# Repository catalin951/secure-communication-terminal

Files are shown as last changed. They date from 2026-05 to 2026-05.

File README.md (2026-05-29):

# Secure Communication Terminal 📻🔒

A fully digital, hardware-secured wireless communication device based on the ESP32 microcontroller. Unlike a classic analog radio station, this device allows real-time voice capture, P2P transmission, and playback **only** if the user passes a biometric authentication filter. 

The system utilizes an ESP32 for processing, an AS608 fingerprint sensor for Zero-Trust access control, and dedicated I2S peripherals for pure digital audio transmission via the ESP-NOW protocol.

## ⚠️ CRITICAL SECURITY CONFIGURATION ⚠️

If you are cloning this repository to build your own terminals, you **MUST** update the following network and security variables in `src/main.cpp` before flashing the code:

1. **Target MAC Address (`peerAddress`):** ESP-NOW requires the exact physical MAC address of the destination device. You must change the `peerAddress[]` array in the code of "Terminal A" to match the MAC of "Terminal B", and vice versa.
2. **AES-128 Secret Key (`secretKey`):** The system uses ESP-NOW's native MAC-layer encryption. You **MUST** change the default 16-byte `secretKey[16]` array to your own random hex values. This key acts as your Pre-Shared Key (PMK) and must be identical on both devices to establish a secure link. Do not use the default repository key!

## Hardware Requirements

To build one terminal, you need the following components:
* 1x **ESP32 DevKit V1** (WROOM-32)
* 1x **AS608** Optical Fingerprint Sensor (UART)
* 1x **INMP441** Digital Omnidirectional Microphone (I2S)
* 1x **MAX98357A** Class D Audio Amplifier (I2S)
* 1x **SSD1306** 0.96" Monochrome OLED Display (I2C)
* 1x 1W Mini Speaker (Analog)
* 3x Tactile Push Buttons (PTT, Admin, Reset)
* 1x Battery Holder (4x AA slots) + 4x NiMH 1.2V Rechargeable Cells
* Custom Enclosure / Breadboard Assembly

## Pinout Mapping

| Component | ESP32 Pin | Signal Type |
| :--- | :--- | :--- |
| **Power (VIN)** | `VIN` | 4.8V Raw Power (Amp & ESP32) |
| **AS608 (RX/TX)** | `D16` / `D17` | UART2 |
| **INMP441 (WS/SCK/SD)** | `D33` / `D18` / `D32` | I2S0 (Microphone) |
| **MAX98357A (WS/BCLK/DIN)** | `D26` / `D27` / `D14` | I2S1 (Amplifier) |
| **SSD1306 (SDA/SCL)** | `D21` / `D22` | I2C |
| **PTT Button** | `D13` | GPIO (INPUT_PULLUP) |
| **Reset Button** | `D19` | GPIO (INPUT_PULLUP) |
| **Admin Button** | `D23` | GPIO (INPUT_PULLUP) |

## Access Control & FSM Logic

The terminal operates based on a strict Finite State Machine (FSM):
* **ST_LOCKED:** The device is isolated. The amplifier is muted (injecting digital zeroes to prevent hiss), and the system waits for biometric validation. Incoming transmissions trigger a hardware beep but audio is blocked.
* **ST_UNLOCKED:** Reached after a valid General User fingerprint match. Unlocks full Two-Way communication for a 2-minute session.
* **ST_ADMIN:** Triggered exclusively by Fingerprint ID 1. Allows enrollment of new users (short press) or complete database wipe (long press).
* **ST_TRANSMIT:** Half-Duplex mode. Pushing the PTT button samples 32-bit audio from the INMP441, truncates it to 16-bit to maximize the ESP-NOW payload (240 bytes), and streams it over the encrypted link. 

## Development & Compilation

This project is built using **PlatformIO**. 
1. Clone the repository.
2. Open the project folder in VS Code with the PlatformIO extension installed.
3. Update the MAC addresses and AES keys.
4. Compile and upload to your ESP32 boards using `Upload`.
5. Note: The project leverages the `driver/i2s_std.h` API from the ESP-IDF natively within the Arduino framework.

## Additional Links:
1. Page with more information about the project: https://ocw.cs.pub.ro/courses/pm/prj2026/theodor_ioan.buliga/catalin.manole1211
2. Demo of the project: https://www.youtube.com/shorts/ny9w-C_flPQ
## License

This project is licensed under the [MIT License](LICENSE) - see the LICENSE file for details.

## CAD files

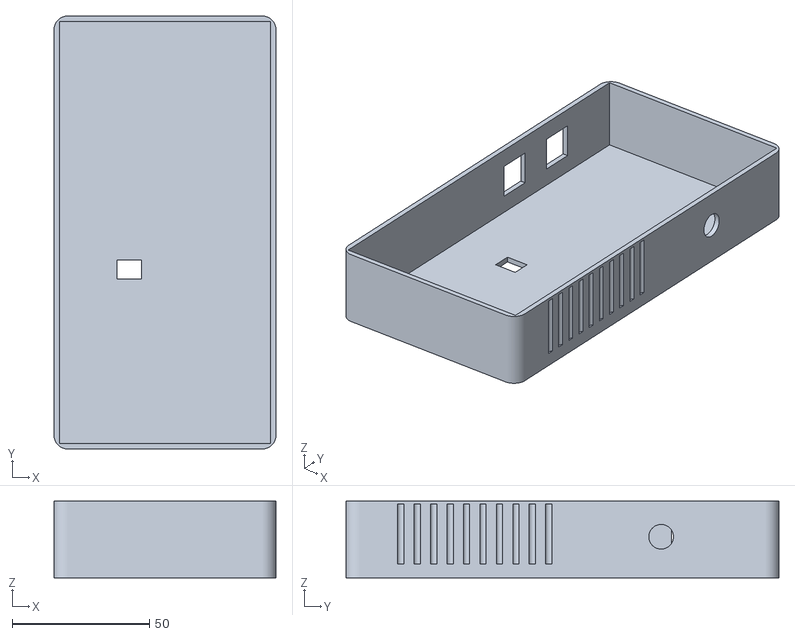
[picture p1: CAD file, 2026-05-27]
enclosure/body.stl
81.0 x 158.0 x 28.0

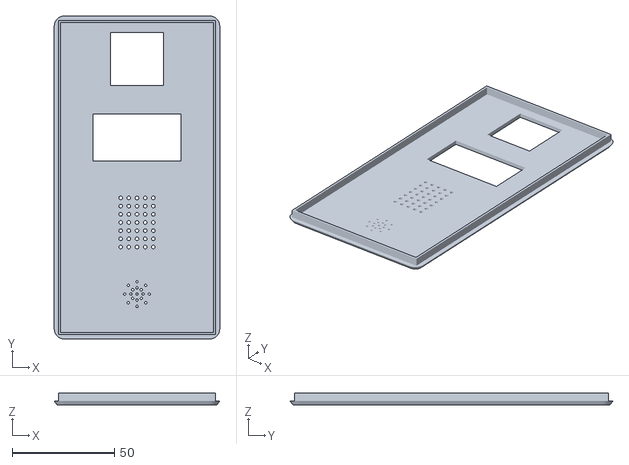
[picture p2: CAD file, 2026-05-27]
enclosure/cover.stl
81.0 x 158.0 x 6.00

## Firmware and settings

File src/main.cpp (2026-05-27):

#include <Arduino.h>
#include <Wire.h>
#include <Adafruit_GFX.h>
#include <Adafruit_SSD1306.h>
#include <Adafruit_Fingerprint.h>
#include "driver/i2s_std.h"
#include "driver/gpio.h"
#include "freertos/FreeRTOS.h"
#include "freertos/task.h"
#include "freertos/queue.h"
#include <esp_now.h>
#include <WiFi.h>

// 1. ESP-NOW TARGET CONFIGURATION
// uint8_t peerAddress[] = {0x88, 0xF1, 0x55, 0x31, 0x81, 0x64};
// const char* myName = "BRAVO";

uint8_t peerAddress[] = {0x88, 0xF1, 0x55, 0x32, 0x75, 0xCC};
const char* myName = "ALPHA";

// Secret AES-128 key - 16 bytes!
// Must be identical on both devices
uint8_t secretKey[16] = {0x1A, 0x2B, 0x3C, 0x4D, 0x5E, 0x6F, 0x70, 0x81, 0x92, 0xA3, 0xB4, 0xC5, 0xD6, 0xE7, 0xF8, 0x09};

// 2. HARDWARE CONFIGURATION

// OLED
#define SCREEN_WIDTH 128
#define SCREEN_HEIGHT 64
Adafruit_SSD1306 display(SCREEN_WIDTH, SCREEN_HEIGHT, &Wire, -1);

// FINGERPRINT
#define FP_RX 16
#define FP_TX 17
HardwareSerial fpSerial(2);
Adafruit_Fingerprint finger = Adafruit_Fingerprint(&fpSerial);

// I2S MIC
#define PIN_I2S_WS   GPIO_NUM_33
#define PIN_I2S_SCK  GPIO_NUM_18
#define PIN_I2S_SD   GPIO_NUM_32
#define I2S_PORT_MIC I2S_NUM_0

// I2S SPEAKER
#define PIN_SPK_WS   GPIO_NUM_26
#define PIN_SPK_BCLK GPIO_NUM_27
#define PIN_SPK_DIN  GPIO_NUM_14
#define I2S_PORT_SPK I2S_NUM_1

i2s_chan_handle_t rx_handle = NULL;
i2s_chan_handle_t tx_handle = NULL;

// BUTTONS
#define PIN_BTN_PTT   13
#define PIN_BTN_RESET 19
#define PIN_BTN_ADMIN 23

// 3. SYSTEM AND NETWORK VARIABLES
enum SystemState { STATE_LOCKED, STATE_WAIT_ADMIN, STATE_ADMIN_MENU, STATE_LIVE_STREAM };
SystemState currentState = STATE_LOCKED;

// UI Logic
enum UIMode { UI_NONE, UI_SENDING, UI_RECEIVING, UI_RECEIVED_PACKET };
UIMode currentUI = UI_NONE;
unsigned long lastPacketTime = 0;

// Async Radio Packet Tracker for Locked Notification
volatile unsigned long lastPacketRxTime = 0;

// Admin Logic Variables
unsigned long adminSessionStart = 0;
bool adminBtnPressed = false;
unsigned long adminBtnPressStart = 0;

// Audio packet structure (Max 250 bytes for ESP-NOW)
#define AUDIO_SAMPLES 120 
typedef struct {
    int16_t audioData[AUDIO_SAMPLES];
} audio_packet_t;

audio_packet_t txPacket;
esp_now_peer_info_t peerInfo;

// Queue for received audio
QueueHandle_t audioQueue;

// 4. FUNCTIONS AND CALLBACKS

void setupI2S() {
    // Config Mic (I2S RX)
    i2s_chan_config_t rx_chan_cfg = I2S_CHANNEL_DEFAULT_CONFIG(I2S_PORT_MIC, I2S_ROLE_MASTER);
    i2s_new_channel(&rx_chan_cfg, NULL, &rx_handle);
    i2s_std_config_t rx_std_cfg = {
        .clk_cfg = I2S_STD_CLK_DEFAULT_CONFIG(16000), 
        .slot_cfg = I2S_STD_PHILIPS_SLOT_DEFAULT_CONFIG(I2S_DATA_BIT_WIDTH_32BIT, I2S_SLOT_MODE_MONO), 
        .gpio_cfg = { .mclk = I2S_GPIO_UNUSED, .bclk = PIN_I2S_SCK, .ws = PIN_I2S_WS, .dout = I2S_GPIO_UNUSED, .din = PIN_I2S_SD, .invert_flags = {0} },
    };
    i2s_channel_init_std_mode(rx_handle, &rx_std_cfg);
    i2s_channel_enable(rx_handle);

    // Config Speaker (I2S TX)
    i2s_chan_config_t tx_chan_cfg = I2S_CHANNEL_DEFAULT_CONFIG(I2S_PORT_SPK, I2S_ROLE_MASTER);
    i2s_new_channel(&tx_chan_cfg, &tx_handle, NULL);
    i2s_std_config_t tx_std_cfg = {
        .clk_cfg = I2S_STD_CLK_DEFAULT_CONFIG(16000), 
        .slot_cfg = I2S_STD_PHILIPS_SLOT_DEFAULT_CONFIG(I2S_DATA_BIT_WIDTH_16BIT, I2S_SLOT_MODE_MONO), 
        .gpio_cfg = { .mclk = I2S_GPIO_UNUSED, .bclk = PIN_SPK_BCLK, .ws = PIN_SPK_WS, .dout = PIN_SPK_DIN, .din = I2S_GPIO_UNUSED, .invert_flags = {0} },
    };
    i2s_channel_init_std_mode(tx_handle, &tx_std_cfg);
}

// ESP-NOW Receive Callback
void OnDataRecv(const esp_now_recv_info_t *esp_now_info, const uint8_t *incomingData, int len) {
    if (len == sizeof(audio_packet_t)) {
        lastPacketRxTime = millis(); // Track incoming traffic timestamp globally
        
        // Only queue audio data if the system is unlocked and live
        if (currentState == STATE_LIVE_STREAM) {
            audio_packet_t rxPacket;
            memcpy(&rxPacket, incomingData, sizeof(rxPacket));
            xQueueSendFromISR(audioQueue, &rxPacket, NULL);
        }
    }
}

// MASTER UI DRAWING FUNCTION
void drawUI(const char* headerTitle, const char* mainText, const char* footerText) {
    display.clearDisplay();
    
    // 1. Header Area
    display.setTextSize(1);
    display.setTextColor(WHITE);
    display.setCursor(0, 0);
    display.print(headerTitle); 
    display.print(" | "); 
    display.print(myName);
    display.drawLine(0, 10, 128, 10, WHITE);
    
    // 2. Main Body Area
    display.setTextSize(2);
    int textWidth = strlen(mainText) * 12; 
    int xPos = (128 - textWidth) / 2;
    if (xPos < 0) xPos = 0; 
    display.setCursor(xPos, 25);
    display.print(mainText);
    
    // 3. Footer Area
    display.drawLine(0, 52, 128, 52, WHITE);
    display.setTextSize(1);
    display.setCursor(0, 55);
    display.print(footerText);
    
    display.display();
}

void drawLockedScreen() {
    drawUI("TERMINAL NAME", "LOCKED", "Scan finger to unlock");
}

void drawAdminMenu() {
    drawUI("ADMIN MENU", "SYSTEM OK", "1x: Add | 3s: Delete");
}

bool enrollRoutine(uint8_t id) {
    int p = -1;
    drawUI("ENROLL 1/3", "PUT FINGER", "Scan ID 2");
    
    while (p != FINGERPRINT_OK) {
        p = finger.getImage();
        if (digitalRead(PIN_BTN_RESET) == LOW) ESP.restart(); 
    }
    p = finger.image2Tz(1);
    if (p != FINGERPRINT_OK) return false;
    
    drawUI("ENROLL 2/3", "LIFT", "Wait for scanner...");
    delay(2000);
    p = 0;
    while (p != FINGERPRINT_NOFINGER) {
        p = finger.getImage();
    }
    
    drawUI("ENROLL 3/3", "TAP AGAIN", "Confirming...");
    p = -1;
    while (p != FINGERPRINT_OK) {
        p = finger.getImage();
        if (digitalRead(PIN_BTN_RESET) == LOW) ESP.restart();
    }
    p = finger.image2Tz(2);
    if (p != FINGERPRINT_OK) return false;
    
    p = finger.createModel();
    if (p != FINGERPRINT_OK) return false;
    
    p = finger.storeModel(id);
    if (p != FINGERPRINT_OK) return false;
    
    return true;
}

// 5. SETUP
void setup() {
    Serial.begin(115200);
    delay(1000);

    pinMode(PIN_BTN_PTT, INPUT_PULLUP);
    pinMode(PIN_BTN_RESET, INPUT_PULLUP);
    pinMode(PIN_BTN_ADMIN, INPUT_PULLUP);

    if(!display.begin(SSD1306_SWITCHCAPVCC, 0x3C)) Serial.println("[DEBUG] OLED Error!");
    drawLockedScreen();

    fpSerial.begin(57600, SERIAL_8N1, FP_RX, FP_TX);
    audioQueue = xQueueCreate(10, sizeof(audio_packet_t));

    WiFi.mode(WIFI_STA);
    WiFi.disconnect();
    esp_now_init();
    
    esp_now_set_pmk(secretKey);
    esp_now_register_recv_cb(OnDataRecv);
    
    memcpy(peerInfo.peer_addr, peerAddress, 6);
    peerInfo.channel = 0;  
    peerInfo.encrypt = true; 
    memcpy(peerInfo.lmk, secretKey, 16); 
    
    esp_now_add_peer(&peerInfo);

    setupI2S();
}

// 6. MAIN LOOP
void loop() {
    if (digitalRead(PIN_BTN_RESET) == LOW) {
        ESP.restart();
    }

    switch (currentState) {
        
        case STATE_LOCKED: {
            // Check if there is active incoming radio traffic right now
            bool isIncoming = (millis() - lastPacketRxTime < 500);
            static bool lastIncomingState = false;

            // Update UI dynamically if transmission state changes while locked
            if (isIncoming != lastIncomingState) {
                lastIncomingState = isIncoming;
                if (isIncoming) {
                    drawUI("ALERT", "INCOMING", "Scan finger to listen!");
                    
                    // Generate a quick hardware alert beep tone
                    i2s_channel_enable(tx_handle);
                    int16_t alertTone[AUDIO_SAMPLES];
                    for(int i = 0; i < AUDIO_SAMPLES; i++) {
                        alertTone[i] = (i % 20 < 10) ? 4000 : -4000; // 800Hz square wave
                    }
                    size_t w;
                    // Play 8 short bursts for an audible "ping" notification
                    for(int bursts = 0; bursts < 8; bursts++) {
                        i2s_channel_write(tx_handle, alertTone, sizeof(alertTone), &w, portMAX_DELAY);
                    }
                    i2s_channel_disable(tx_handle); // Disable amp again to save power
                } else {
                    drawLockedScreen();
                }
            }

            // Trigger Admin Login
            if (digitalRead(PIN_BTN_ADMIN) == LOW) {
                drawUI("ADMIN AUTH", "TAP ADMIN", "Place Master Finger");
                currentState = STATE_WAIT_ADMIN;
                adminSessionStart = millis(); 
                delay(300); 
                break;
            }

            // Normal User Login
            uint8_t p = finger.getImage();
            if (p == FINGERPRINT_OK) {
                if (finger.image2Tz() == FINGERPRINT_OK && finger.fingerFastSearch() == FINGERPRINT_OK) {
                    i2s_channel_enable(tx_handle); 
                    currentState = STATE_LIVE_STREAM;
                    currentUI = UI_NONE; 
                }
            }
            break;
        }

        case STATE_WAIT_ADMIN: {
            uint8_t p = finger.getImage();
            if (p == FINGERPRINT_OK) {
                if (finger.image2Tz() == FINGERPRINT_OK && finger.fingerFastSearch() == FINGERPRINT_OK) {
                    if (finger.fingerID == 1) { 
                        currentState = STATE_ADMIN_MENU;
                        adminSessionStart = millis(); 
                        drawAdminMenu();
                    } else {
                        drawUI("SECURITY", "DENIED", "Unauthorized User");
                        delay(2000);
                        currentState = STATE_LOCKED;
                        drawLockedScreen();
                    }
                }
            }
            if (millis() - adminSessionStart > 10000 && currentState != STATE_ADMIN_MENU) {
                currentState = STATE_LOCKED;
                drawLockedScreen();
            }
            break;
        }

        case STATE_ADMIN_MENU: {
            if (millis() - adminSessionStart > 300000) {
                currentState = STATE_LOCKED;
                drawLockedScreen();
                break;
            }

            if (digitalRead(PIN_BTN_ADMIN) == LOW) {
                if (!adminBtnPressed) {
                    adminBtnPressed = true;
                    adminBtnPressStart = millis();
                }
            } else {
                if (adminBtnPressed) {
                    unsigned long pressDuration = millis() - adminBtnPressStart;
                    adminBtnPressed = false;
                    adminSessionStart = millis(); 

                    if (pressDuration >= 3000) { 
                        if (finger.deleteModel(2) == FINGERPRINT_OK) {
                            drawUI("ADMIN MODE", "DELETED", "User removed");
                        } else {
                            drawUI("ADMIN MODE", "ERROR", "Delete failed");
                        }
                        delay(2000);
                        drawAdminMenu();
                    } 
                    else if (pressDuration > 50) { 
                        if (enrollRoutine(2)) { 
                            drawUI("ADMIN MODE", "ADDED", "User enrolled");
                        } else {
                            drawUI("ADMIN MODE", "ERROR", "Enroll failed");
                        }
                        delay(2000);
                        drawAdminMenu();
                    }
                }
            }
            break;
        }

        case STATE_LIVE_STREAM: {
            bool isPTTPressed = (digitalRead(PIN_BTN_PTT) == LOW);
            UIMode targetUI = currentUI; 

            if (isPTTPressed) {
                targetUI = UI_SENDING;
                
                int32_t micBuffer[AUDIO_SAMPLES];
                size_t bytes_read = 0;
                esp_err_t err = i2s_channel_read(rx_handle, micBuffer, sizeof(micBuffer), &bytes_read, portMAX_DELAY);
                
                if (err == ESP_OK && bytes_read > 0) {
                    for (int i = 0; i < AUDIO_SAMPLES; i++) {
                        txPacket.audioData[i] = (int16_t)(micBuffer[i] >> 16);
                    }
                    esp_now_send(peerAddress, (uint8_t *) &txPacket, sizeof(txPacket));
                }
            } 
            else {
                audio_packet_t rxPacket;
                size_t w;
                
                if (xQueueReceive(audioQueue, &rxPacket, 0) == pdTRUE) {
                    targetUI = UI_RECEIVED_PACKET;
                    lastPacketTime = millis();
                    i2s_channel_write(tx_handle, rxPacket.audioData, AUDIO_SAMPLES * sizeof(int16_t), &w, portMAX_DELAY);
                } else {
                    if (millis() - lastPacketTime > 200) {
                        targetUI = UI_RECEIVING;
                    }
                    int16_t silence[AUDIO_SAMPLES] = {0};
                    i2s_channel_write(tx_handle, silence, sizeof(silence), &w, portMAX_DELAY);
                }
            }

            if (targetUI != currentUI) {
                currentUI = targetUI;
                
                if (currentUI == UI_SENDING) {
                    drawUI("TRANSMIT", ">>> TALK", "Streaming audio...");
                } else if (currentUI == UI_RECEIVING) {
                    drawUI("COMMS ONLINE", "READY", "Press PTT to transmit");
                } else if (currentUI == UI_RECEIVED_PACKET) {
                    drawUI("RECEIVE", "<<< VOICE", "Decrypting AES-128...");
                }
            }
            break;
        }
    }
}
